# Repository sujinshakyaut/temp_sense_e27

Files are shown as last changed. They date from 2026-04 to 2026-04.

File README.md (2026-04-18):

# Thermal Monitoring Module (E27)





[]()

A compact multi-channel temperature sensing PCB built around the TI MSPM0C1104 microcontroller with CAN FD communication. Designed to be later integrated on a voltage tap board that mounts directly onto the Orion BMS module, providing up to 24 analog temperature inputs per tapboard or breakout board multiplexed through a 3 ADC channel with robust power protection for automotive and industrial environments.

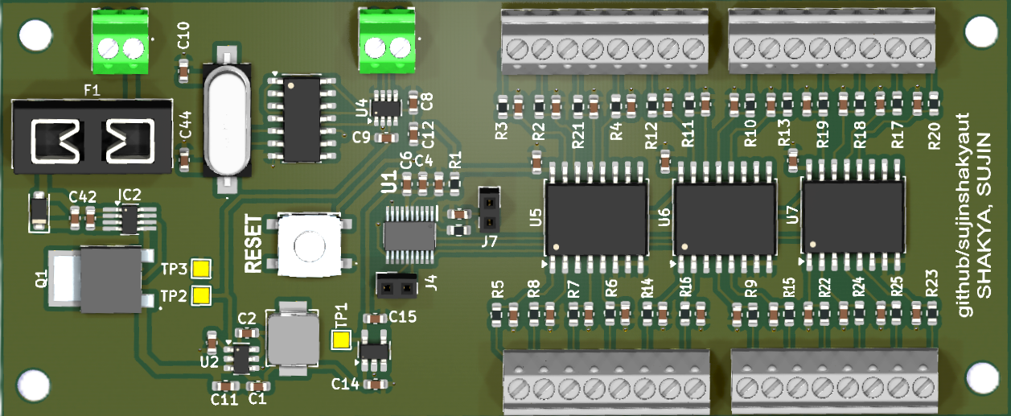
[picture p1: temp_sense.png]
Temperature Sensor Board


## Table of Contents

- [Background](#background)
- [NTC Thermistors & Steinhart-Hart](#ntc-thermistors--steinhart-hart)
- [Validation & Troubleshooting](#validation--troubleshooting)
- [Features](#features)
- [Contributing](#contributing)
- [License](#license)

## Background

This is a redesigned temperature sensing board intended to be integrated with a voltage tap board on the Orion BMS module, providing cell temperature monitoring across the battery pack. 

The main Orion BMS is limited to 8 internal thermistor inputs, which is insufficient for large-scale battery packs. To achieve full coverage, we integrated the Orion Thermistor Expansion Module, scaling our monitoring capacity to 60+ individual cells. This expansion node digitizes localized analog temperatures and broadcasts them via CANbus to the main unit. This architecture not only meets the capacity requirements of the accumulator but also ensures clean data transmission and minimizes wiring complexity within the high-voltage enclosure.

This is fine

The board consolidates power regulation, input protection, analog multiplexing, and CAN FD communication onto a single compact PCB. A three-stage power supply has been implemented due to potential 60V voltage spikes from the battery module. Power input is protected by an LM74500 ideal diode controller and an SMF24CA TVS diode, with the AP63205 buck converter stepping down to 5 V and a TPS7A03 LDO providing a clean 3.3 V rail. A fuse is included for extra protection.

The CLV4051A 8:1 analog multiplexer allows a single ADC input on the MSPM0C to scan up to 8 temperature sensor channels sequentially, reducing pin count. The MCP2517FD provides CAN FD connectivity over SPI.

## NTC Thermistors & Steinhart-Hart

This board interfaces with Negative Temperature Coefficient (NTC) thermistors (typically 10 kΩ at 25°C). The thermistors are placed in a voltage divider circuit with a known 10 kΩ bias resistor. Because the resistance curve of an NTC is highly non-linear, the firmware utilizes the Steinhart-Hart equation for accurate conversion from resistance to temperature across the accumulator's operating range:

$$\frac{1}{T} = A + B \ln(R) + C (\ln(R))^3$$

Where:
* T = Temperature in Kelvin
* R = Measured resistance of the thermistor in Ohms
* A, B, C = Steinhart-Hart coefficients provided by the thermistor manufacturer

The MCU reads the 12-bit ADC value, calculates the resistance R via the voltage divider equation, applies the Steinhart-Hart conversion to find Kelvin, and then broadcasts the Celsius equivalent over CAN FD.

## Features

- 24-channel analog temperature input via CLV4051A multiplexers
- CAN FD communication (MCP2517FD over SPI) to Orion BMS
- Wide input voltage range with reverse polarity and TVS protection
- On-board buck + LDO three-stage power supply with 24V voltage regulation
- High-accuracy NTC thermistor reading using Steinhart-Hart conversion
- Screw terminal connectors
- M3 mounting holes for panel or DIN mount

## Contributing

Open an issue or pull request on [GitHub](https://github.com/sujinshakyaut/temp_sense_e27).

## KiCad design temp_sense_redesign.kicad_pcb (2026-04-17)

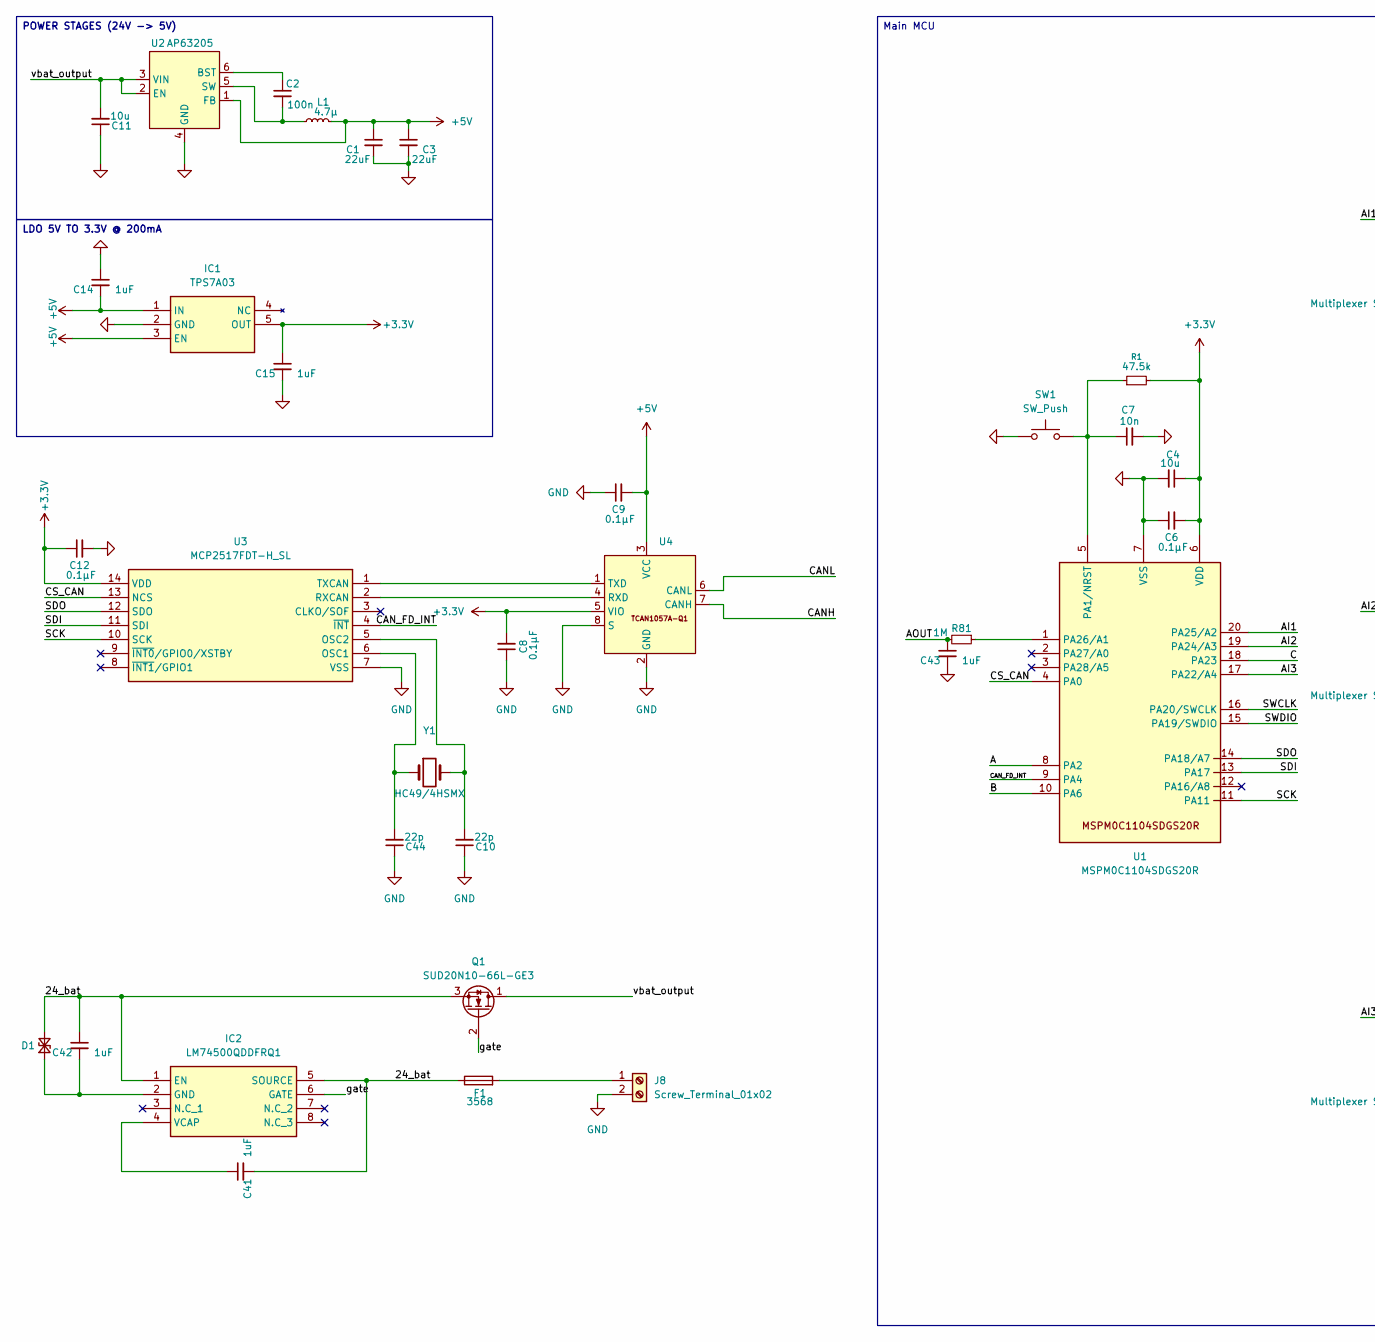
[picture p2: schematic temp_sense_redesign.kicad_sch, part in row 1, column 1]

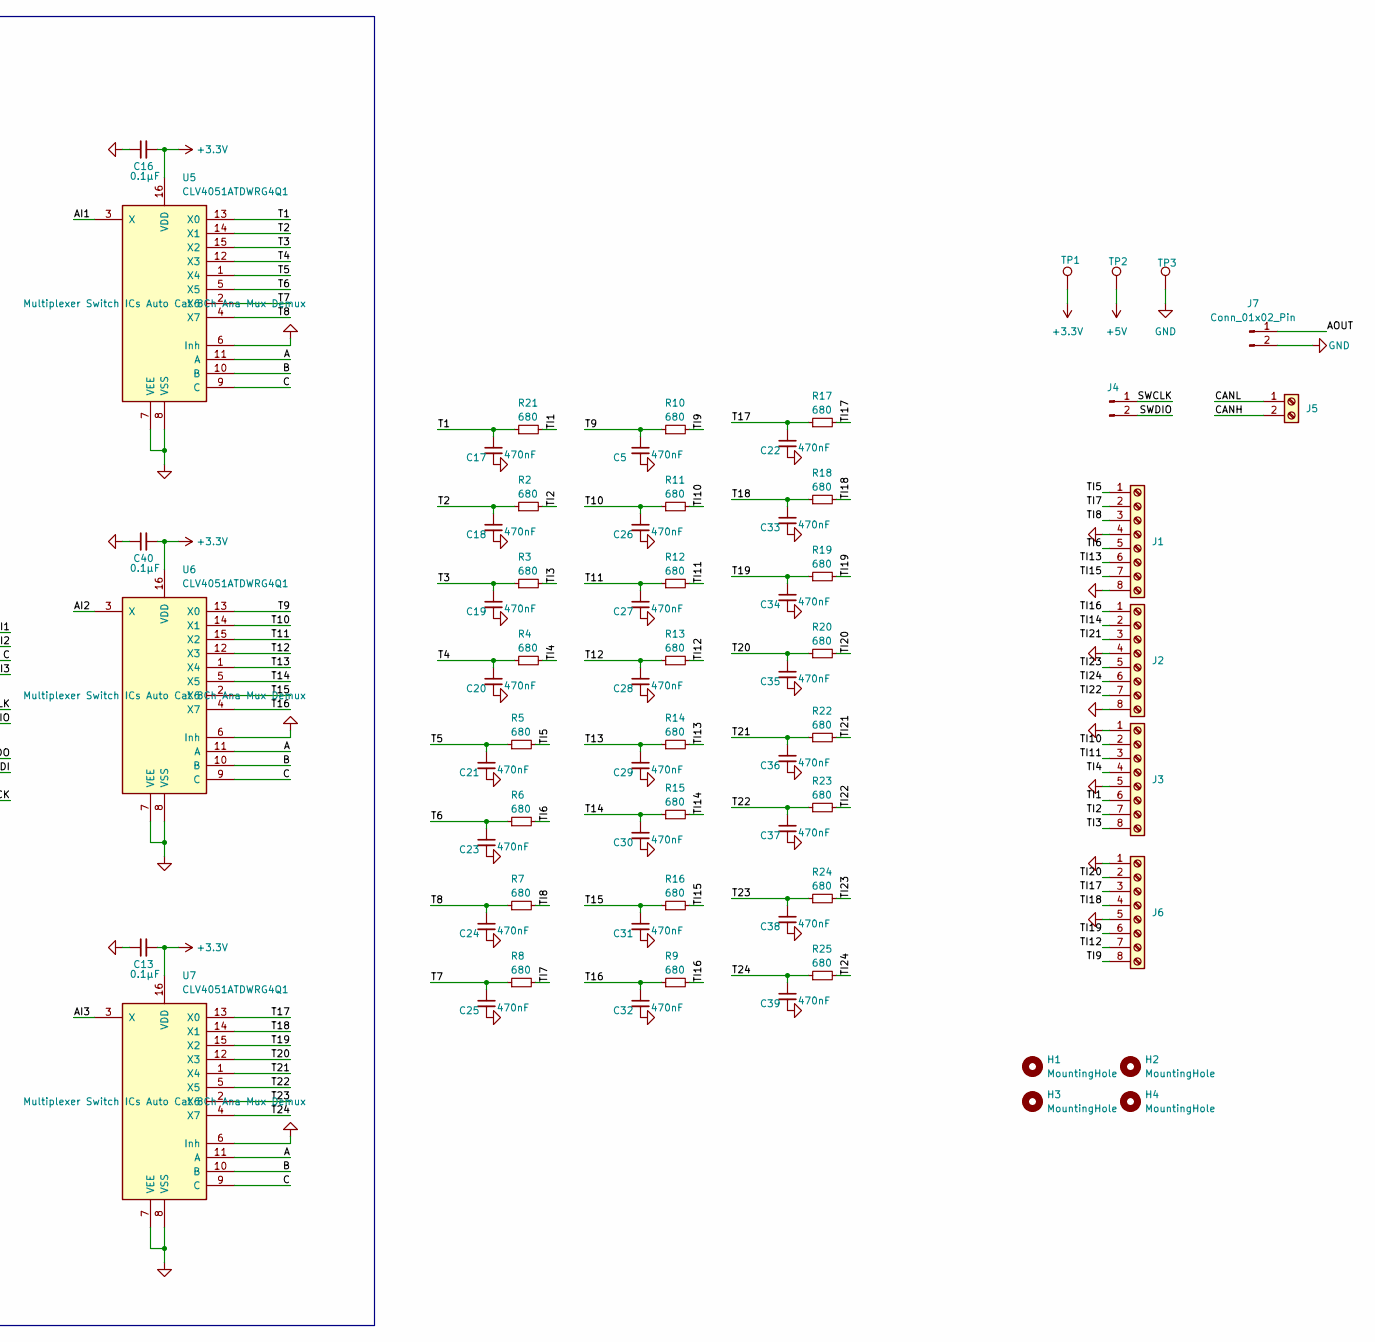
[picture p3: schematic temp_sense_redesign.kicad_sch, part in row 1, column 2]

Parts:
C1, C3: 22uF; C_0603_1608Metric; Mouser P/N 963-MLASG32MSB5226MP
C2: 100n; C_0603_1608Metric; Mouser P/N 810-C1608X8R1H104K
C4: 10u; C_0603_1608Metric; Mouser P/N 81-ZRB18AR6YA106ME1L
C5, C17, C18, C19, C20, C21, C22, C23, C24, C25, C26, C27, C28, C29, C30, C31, C32, C33, C34, C35, C36, C37, C38, C39: 470nF; C_0603_1608Metric; Mouser P/N 81-GXT155R61A474KE1D
C6, C8, C9, C12, C13, C16, C40: 0.1µF; C_0603_1608Metric; Mouser P/N 81-GCM188R71C104KA7J
C7: 10n; C_0603_1608Metric; Mouser P/N 603-CC0603JR7R7BB103
C10, C44: 22p; C_0603_1608Metric; Mouser P/N 81-GCQ0335C1H220JB1D
C11: 10u; C_0603_1608Metric_Pad1.08x0.95mm_HandSolder; Mouser P/N 81-ZRB18AR6YA106ME1L
C14, C15, C41, C42, C43: 1uF; C_0603_1608Metric; Mouser P/N 81-GRM1887R1E105KA2D
D1: Littelfuse SMF24CA; D_SOD-123F; Mouser P/N 576-SMF24CA
F1: 3568; Fuseholder_Blade_Mini_Keystone_3568; Mouser P/N 534-3568
H1, H2, H3, H4: MountingHole; MountingHole_3.2mm_M3
IC1: TPS7A03; SOT-23-5_HandSoldering; Manufacturer_Part_Number TLV74133PDBVR
IC2: LM74500QDDFRQ1; TSOT-23-8_HandSoldering; Mouser P/N 595-LM74500QDDFRQ1
J1, J2, J3, J6: Screw_Terminal_01x08; 1725711; Mouser P/N 490-TB003-500-P03BE
J4, J7: Conn_01x02_Pin; PinSocket_1x02_P2.00mm_Vertical
J5: Screw_Terminal_01x02; 1725656; Mouser P/N 651-1725656
J8: Screw_Terminal_01x02; 1725656
L1: 4.7μ; inductorcustome27; Mouser P/N 70-IHLP2020BZR4R7M1A
Q1: SUD20N10-66L-GE3; SUD20N1066LGE3; Mouser P/N 78-SUD20N10-66L-GE3
R1: 47.5k; R_0603_1608Metric; Mouser P/N 652-CR1206FX-4752ELF
R2, R3, R4, R5, R6, R7, R8, R9, R10, R11, R12, R13, R14, R15, R16, R17, R18, R19, R20, R21, R22, R23, R24, R25: 680; R_0603_1608Metric; Mouser P/N 667-ERJ-3EKF6800V
R81: 1M; R_0603_1608Metric; Mouser P/N 667-ERJ-3EKF1004V
SW1: SW_Push; KSC251JSPDELTALFS; Mouser P/N 611-KSC251JSPDELTALF
TP1, TP2, TP3: TestPoint; TestPoint_Pad_1.5x1.5mm
U1: MSPM0C1104SDGS20R; MSPMOC; Mouser P/N 595-MSPM0C1104SDG20R
U2: AP63205; TSOT-23-6; Mouser P/N 621-AP63205WU-7
U3: MCP2517FDT-H_SL; SOIC-14_3.9x8.7mm_P1.27mm; Mouser P/N 579-MCP2517FD-H/SL
U4: MCP2517FD-H/SL; Texas_DDF0008A_SOT-8_1.6x2.9mm_P0.65mm; Mouser P/N 595-TCAN1057AVDDFRQ1
U5, U6, U7: CLV4051ATDWRG4Q1; SOIC-16W_7.5x10.3mm_P1.27mm; Mouser P/N 595-CLV4051ATDWRG4Q1
Y1: HC49/4HSMX; 830017146; Mouser P/N 710-830017146

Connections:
+3.3V: C4.1, C6.2, C8.2, C12.1, C13.2, C15.1, C16.2, C40.2, IC1.5 (OUT), R1.2, TP1.1, U1.6 (VDD), U3.14 (VDD), U4.5 (VIO), U5.16 (VDD), U6.16 (VDD), U7.16 (VDD)
+5V: C1.1, C3.1, C9.2, C14.2, IC1.1 (IN), IC1.3 (EN), L1.2, TP2.1, U2.1 (FB), U4.3 (VCC)
/24_bat: C41.2, C42.1, D1.2 (A2), F1.1, IC2.1 (EN), IC2.5 (SOURCE), Q1.3 (S)
/A: U1.8 (PA2), U5.11 (A), U6.11 (A), U7.11 (A)
/AI1: U1.20 (PA25/A2), U5.3 (X)
/AI2: U1.19 (PA24/A3), U6.3 (X)
/AI3: U1.17 (PA22/A4), U7.3 (X)
/AOUT: C43.1, J7.1, R81.2
/B: U1.10 (PA6), U5.10 (B), U6.10 (B), U7.10 (B)
/C: U1.18 (PA23), U5.9 (C), U6.9 (C), U7.9 (C)
/CANH: J5.2, U4.7 (CANH)
/CANL: J5.1, U4.6 (CANL)
/CAN_FD_INT: U1.9 (PA4), U3.4 (~INT)
/CS_CAN: U1.4 (PA0), U3.13 (NCS)
/SCK: U1.11 (PA11), U3.10 (SCK)
/SDI: U1.13 (PA17), U3.11 (SDI)
/SDO: U1.14 (PA18/A7), U3.12 (SDO)
/SWCLK: J4.1, U1.16 (PA20/SWCLK)
/SWDIO: J4.2, U1.15 (PA19/SWDIO)
/T1: C17.1, R21.1, U5.13 (X0)
/T2: C18.1, R2.1, U5.14 (X1)
/T3: C19.1, R3.1, U5.15 (X2)
/T4: C20.1, R4.1, U5.12 (X3)
/T5: C21.1, R5.1, U5.1 (X4)
/T6: C23.1, R6.1, U5.5 (X5)
/T7: C25.1, R8.1, U5.2 (X6)
/T8: C24.1, R7.1, U5.4 (X7)
/T9: C5.1, R10.1, U6.13 (X0)
/T10: C26.1, R11.1, U6.14 (X1)
/T11: C27.1, R12.1, U6.15 (X2)
/T12: C28.1, R13.1, U6.12 (X3)
/T13: C29.1, R14.1, U6.1 (X4)
/T14: C30.1, R15.1, U6.5 (X5)
/T15: C31.1, R16.1, U6.2 (X6)
/T16: C32.1, R9.1, U6.4 (X7)
/T17: C22.1, R17.1, U7.13 (X0)
/T18: C33.1, R18.1, U7.14 (X1)
/T19: C34.1, R19.1, U7.15 (X2)
/T20: C35.1, R20.1, U7.12 (X3)
/T21: C36.1, R22.1, U7.1 (X4)
/T22: C37.1, R23.1, U7.5 (X5)
/T23: C38.1, R24.1, U7.2 (X6)
/T24: C39.1, R25.1, U7.4 (X7)
/TI1: J3.6, R21.2
/TI2: J3.7, R2.2
/TI3: J3.8, R3.2
/TI4: J3.4, R4.2
/TI5: J1.1, R5.2
/TI6: J1.5, R6.2
/TI7: J1.2, R8.2
/TI8: J1.3, R7.2
/TI9: J6.8, R10.2
/TI10: J3.2, R11.2
/TI11: J3.3, R12.2
/TI12: J6.7, R13.2
/TI13: J1.6, R14.2
/TI14: J2.2, R15.2
/TI15: J1.7, R16.2
/TI16: J2.1, R9.2
/TI17: J6.3, R17.2
/TI18: J6.4, R18.2
/TI19: J6.6, R19.2
/TI20: J6.2, R20.2
/TI21: J2.3, R22.2
/TI22: J2.7, R23.2
/TI23: J2.5, R24.2
/TI24: J2.6, R25.2
/gate: IC2.6 (GATE), Q1.2 (G)
/vbat_output: C11.2, Q1.1 (D), U2.2 (EN), U2.3 (VIN)
GND: C1.2, C3.2, C4.2, C5.2, C6.1, C7.2, C8.1, C9.1, C10.1, C11.1, C12.2, C13.1, C14.1, C15.2, C16.1, C17.2, C18.2, C19.2, C20.2, C21.2, C22.2, C23.2, C24.2, C25.2, C26.2, C27.2, C28.2, C29.2, C30.2, C31.2, C32.2, C33.2, C34.2, C35.2, C36.2, C37.2, C38.2, C39.2, C40.1, C43.2, C44.1, IC1.2 (GND), J1.4, J1.8, J2.4, J2.8, J3.1, J3.5, J6.1, J6.5, J7.2, J8.2, SW1.1, TP3.1, U1.7 (VSS), U2.4 (GND), U3.7 (VSS), U4.2 (GND), U4.8 (S), U5.6 (Inh), U5.7 (VEE), U5.8 (VSS), U6.6 (Inh), U6.7 (VEE), U6.8 (VSS), U7.6 (Inh), U7.7 (VEE), U7.8 (VSS)
unnamed: C42.2, D1.1 (A1), IC2.2 (GND)
unnamed: C41.1, IC2.4 (VCAP)
unnamed: F1.2, J8.1
unnamed: C7.1, R1.1, SW1.2, U1.5 (PA1/NRST)
unnamed: R81.1, U1.1 (PA26/A1)
unnamed: C2.1, U2.6 (BST)
unnamed: C2.2, L1.1, U2.5 (SW)
unnamed: C44.2, U3.6 (OSC1), Y1.1
unnamed: C10.2, U3.5 (OSC2), Y1.2
unnamed: U3.2 (RXCAN), U4.4 (RXD)
unnamed: U3.1 (TXCAN), U4.1 (TXD)

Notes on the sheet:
LDO 5V TO 3.3V @ 200mA
Main MCU
POWER STAGES (24V -> 5V)

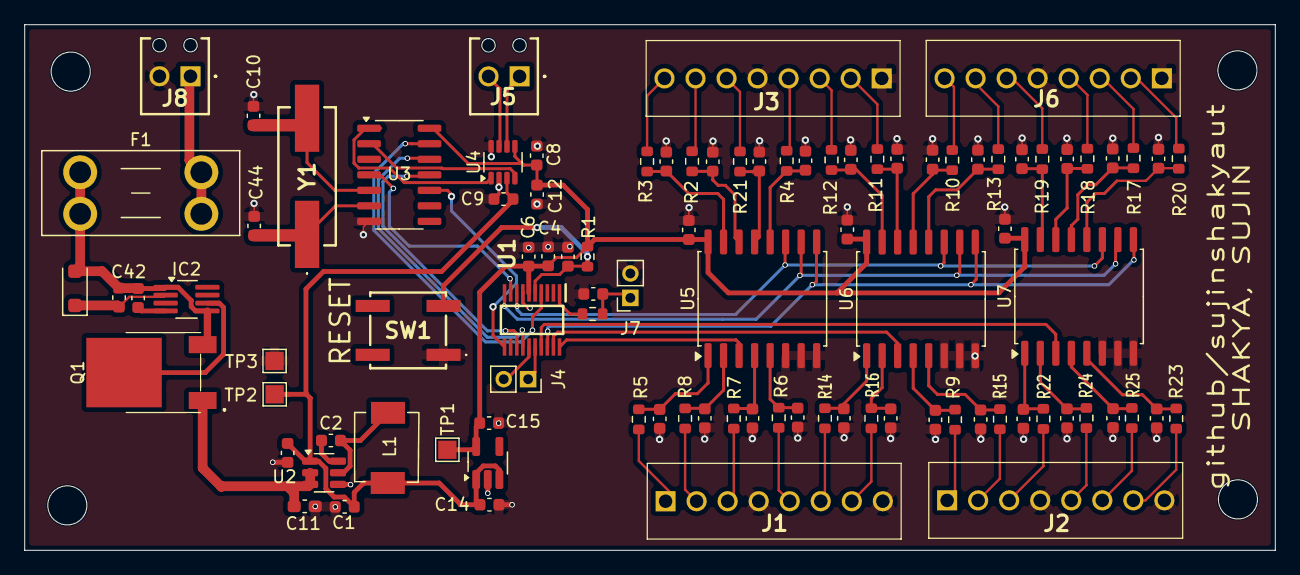
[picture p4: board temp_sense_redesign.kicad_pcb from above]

Board: 2 copper layers, 102.4 x 43.0 mm, 100 parts (0 on the bottom side), 81 nets.

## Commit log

2026-03-28 Update design files, add custom library and footprints
    [830017146.stp, IHLP2020BZ.STEP, temp_sense_redesign.kicad_pcb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]
2026-04-17 Add KiCad .gitignore, remove gerber/backup/cache files from tracking
    [830017146.stp, IHLP2020BZ.STEP, temp_sense_redesign.kicad_pcb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]
2026-04-17 Remove symbol library files and ignore *.kicad_sym
2026-04-17 Add board image, TI and Orion BMS badges, update BMS context in README
2026-04-17 Use higher quality board render image in README
2026-04-17 Revise README for clarity and additional details
    Updated the README to clarify integration with voltage tap board and added details about the three-stage power supply and fuse protection.
2026-04-17 Enhance README with NTC thermistors and troubleshooting info
    Added sections on NTC thermistors and validation troubleshooting to provide detailed information on temperature sensing and system reliability.
2026-04-17 Revise README for temperature sensing PCB details
    Updated description to reflect integration capabilities and increased temperature input support.
2026-04-17 Enhance README with integration details
    Added section on Decentralization and Orion BMS Integration to explain the benefits of the PCB design and its communication method.
2026-04-17 Remove fp-lib-table, sym-lib-table, and old board render PNG
2026-04-17 Increase image width for temperature sensing board
    Updated image size for better visibility in README.
2026-04-17 Revise README with expansion module details and format
    Updated the background section to include details about the Orion Thermistor Expansion Module and its capabilities. Revised the hardware table format and corrected the number of temperature channels supported.

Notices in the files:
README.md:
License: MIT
